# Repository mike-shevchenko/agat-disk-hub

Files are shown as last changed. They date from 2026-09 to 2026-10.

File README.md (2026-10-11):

# agat-disk-hub

KiCad project for Agat/Apple2 140K floppy disk drive connector PCB.

The Agat font used for the texts on the board's front mask resides in https://github.com/mike-shevchenko/retro-tools/tree/master/fonts/

## Использование платы

TODO

## Сборка платы

TODO

## To do

- Silk: надписи на задней стороне вдоль названия проекта сделать Justification: Left.

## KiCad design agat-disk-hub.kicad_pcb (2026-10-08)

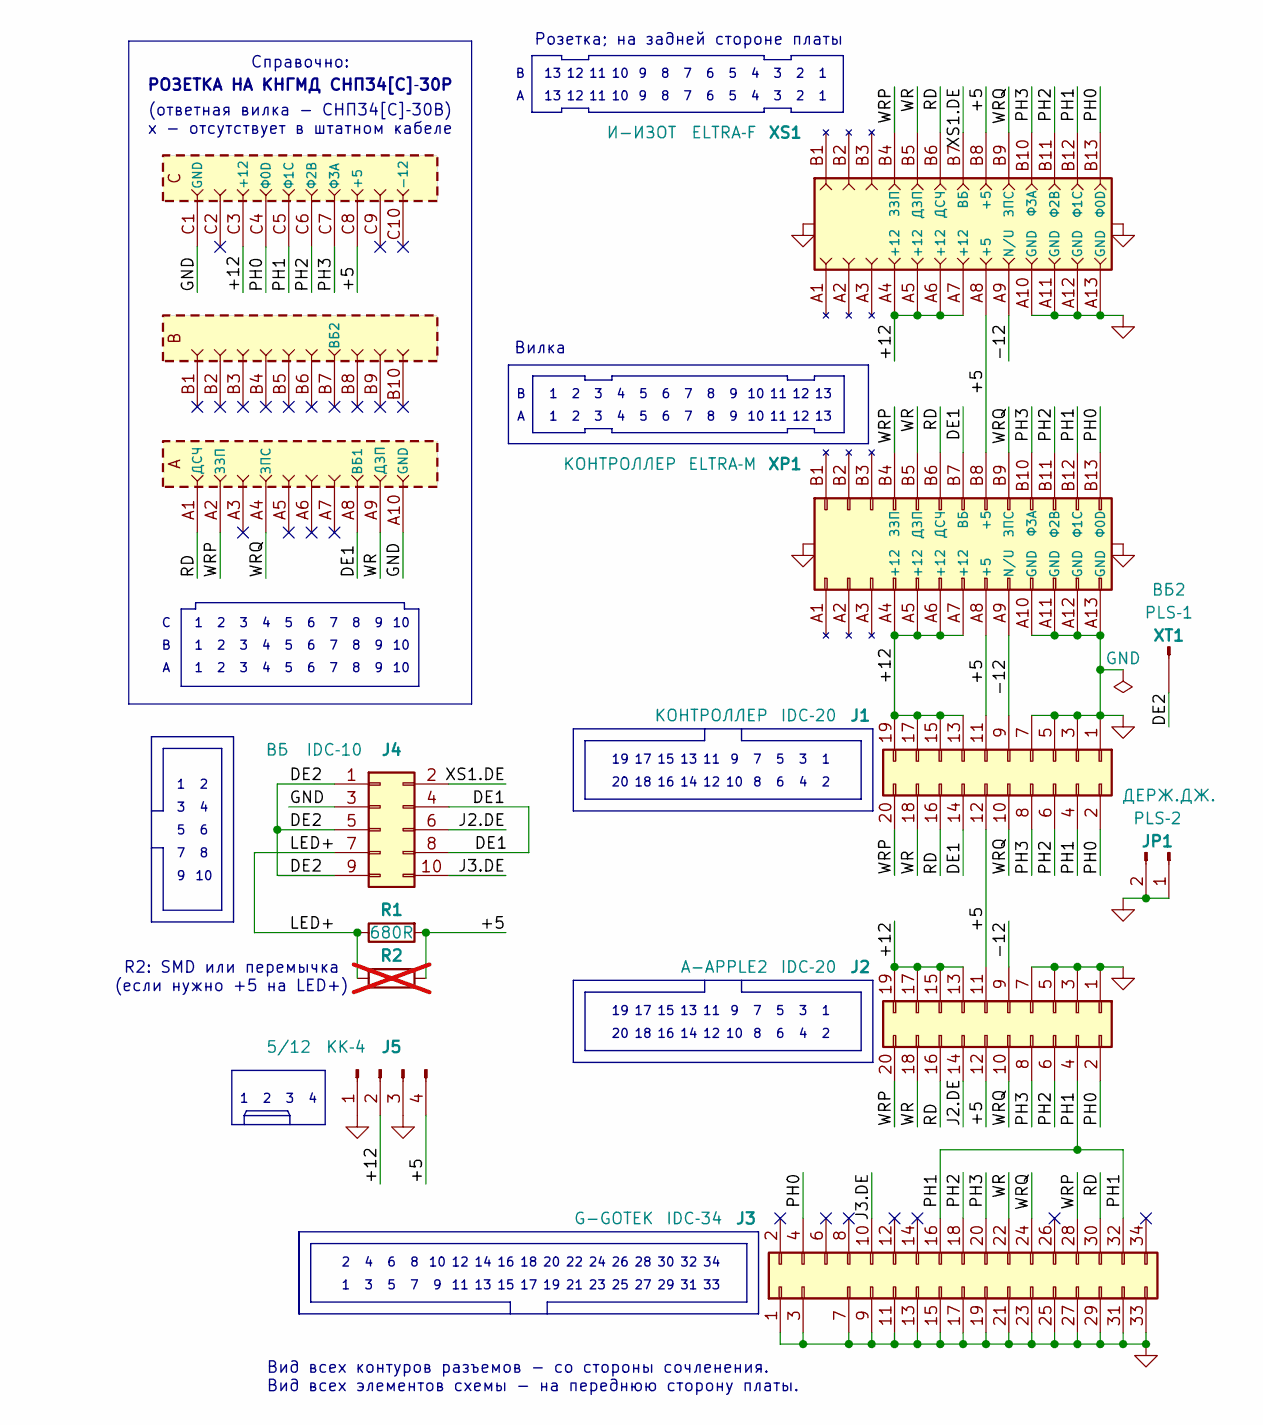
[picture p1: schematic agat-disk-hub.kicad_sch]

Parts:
J1, J2: IDC‐20; IDC-20_header_vertical_rotation180
J3: IDC‐34; IDC-34_header_vertical_rotation0
J4: IDC‐10; IDC-10_header_vertical_rotation270
J5: KK‐4; Molex_KK-4_vertical_rotation0
JP1: PLS‐2; PinHeader_1x02_P2.54mm_Vertical
R1: 680R; R_Axial_DIN0207_L6.3mm_D2.5mm_P10.16mm_Horizontal
R2: 0R; jumper_1206_solder_drop; not fitted
XP1: ELTRA‐M; Eltra-26M
XS1: ELTRA‐F; Eltra-26F
XS404: СНП34-30Р; СНП34С-30
XT1: PLS‐1; PinHeader_1x01_P2.54mm_Vertical

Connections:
/+5: J1.11, J1.12, J2.11, J2.12, J5.4, R1.2, R2.1, XP1.A8 (+5), XP1.B8 (+5), XS1.A8 (+5), XS1.B8 (+5), XS404.C8 (+5)
/+12: J1.13, J1.15, J1.17, J1.19, J2.13, J2.15, J2.17, J2.19, J5.2, XP1.A4 (+12), XP1.A5 (+12), XP1.A6 (+12), XP1.A7 (+12), XS1.A4 (+12), XS1.A5 (+12), XS1.A6 (+12), XS1.A7 (+12), XS404.C3 (+12)
/-12: J1.9, J2.9, XP1.A9 (N/U), XS1.A9 (N/U)
/DE1: J1.14, J4.4, J4.8, XP1.B7 (ВБ), XS404.A8 (ВБ1)
/DE2: J4.1, J4.5, J4.9, XT1.1 (Pin_1_1)
/J2.DE: J2.14, J4.6
/J3.DE: J3.10, J4.10
/LED+: J4.7, R1.1, R2.2
/PH0: J1.2, J2.2, J3.4, XP1.B13 (Ф0D), XS1.B13 (Ф0D), XS404.C4 (Ф0D)
/PH1: J1.4, J2.4, J3.16, J3.32, XP1.B12 (Ф1C), XS1.B12 (Ф1C), XS404.C5 (Ф1C)
/PH2: J1.6, J2.6, J3.18, XP1.B11 (Ф2B), XS1.B11 (Ф2B), XS404.C6 (Ф2B)
/PH3: J1.8, J2.8, J3.20, XP1.B10 (Ф3A), XS1.B10 (Ф3A), XS404.C7 (Ф3A)
/RD: J1.16, J2.16, J3.30, XP1.B6 (ДСЧ), XS1.B6 (ДСЧ), XS404.A1 (ДСЧ)
/WR: J1.18, J2.18, J3.22, XP1.B5 (ДЗП), XS1.B5 (ДЗП), XS404.A9 (ДЗП)
/WRP: J1.20, J2.20, J3.28, XP1.B4 (ЗЗП), XS1.B4 (ЗЗП), XS404.A2 (ЗЗП)
/WRQ: J1.10, J2.10, J3.24, XP1.B9 (ЗПС), XS1.B9 (ЗПС), XS404.A4 (ЗПС)
/XS1.DE: J4.2, XS1.B7 (ВБ)
GND: J1.1, J1.3, J1.5, J1.7, J2.1, J2.3, J2.5, J2.7, J3.1, J3.3, J3.7, J3.9, J3.11, J3.13, J3.15, J3.17, J3.19, J3.21, J3.23, J3.25, J3.27, J3.29, J3.31, J3.33, J4.3, J5.1, J5.3, JP1.1, JP1.2, XP1.A10 (GND), XP1.A11 (GND), XP1.A12 (GND), XP1.A13 (GND), XP1.SCREW_L, XP1.SCREW_R, XS1.A10 (GND), XS1.A11 (GND), XS1.A12 (GND), XS1.A13 (GND), XS1.SCREW_L, XS1.SCREW_R, XS404.A10 (GND), XS404.C1 (GND)

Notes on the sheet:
Розетка; на задней стороне платы
Справочно:
(ответная вилка - СНП34[С]‐30В) х - отсутствует в штатном кабеле
Вилка
РОЗЕТКА НА КНГМД СНП34[С]‐30Р
Вид всех контуров разъемов - со стороны сочленения. Вид всех элементов схемы - на переднюю сторону платы.
R2: SMD или перемычка (если нужно +5 на LED+)

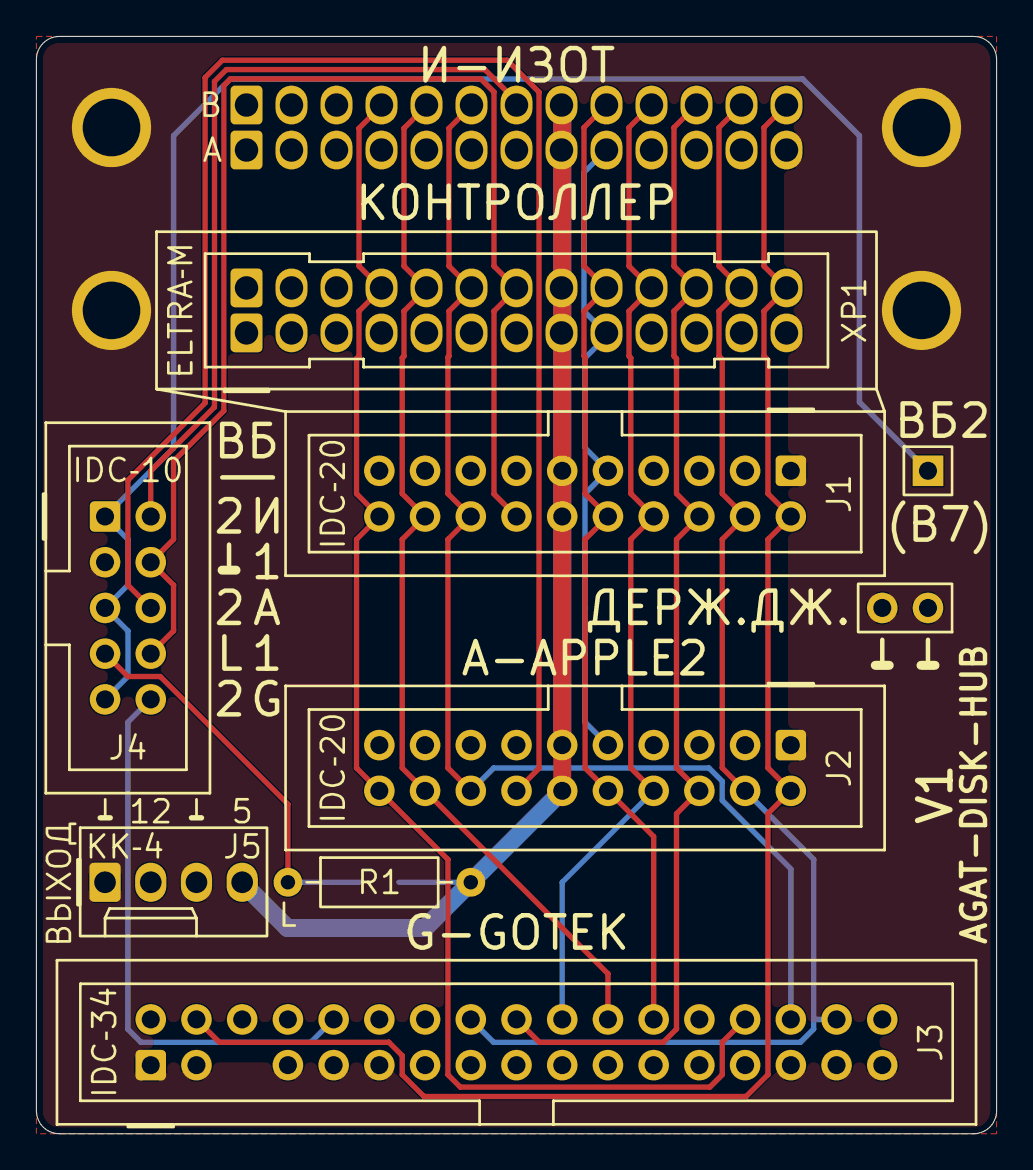
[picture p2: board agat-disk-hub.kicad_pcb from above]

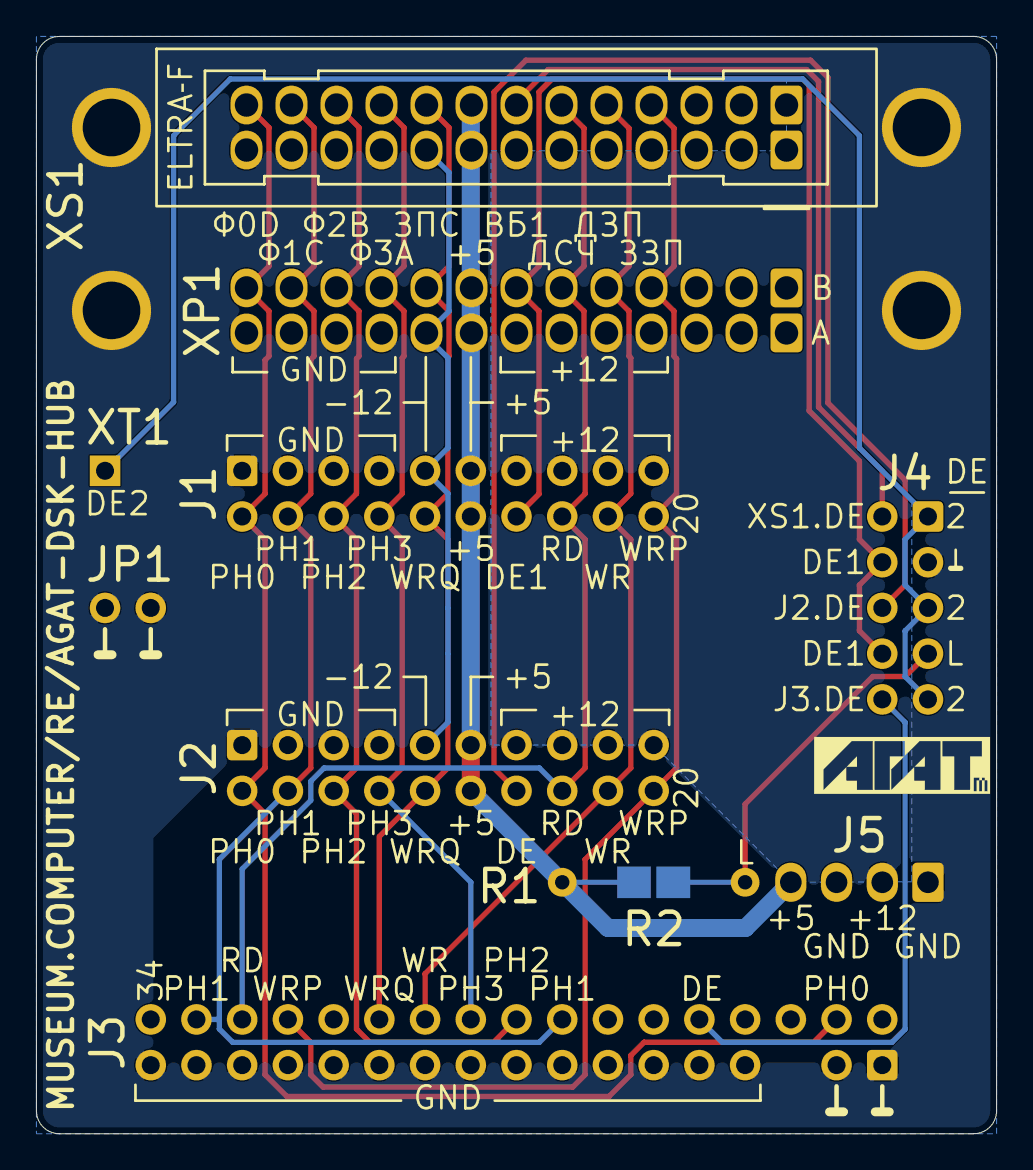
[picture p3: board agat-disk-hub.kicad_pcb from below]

Board: 2 copper layers, 53.3 x 61.0 mm, 11 parts (2 on the bottom side), 18 nets.

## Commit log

2026-09-17 add initial PCB impl: one FDC connector, small font
    [agat_disk_adapter.kicad_pcb, agat_disk_adapter.kicad_sch]
2026-09-19 add second FDC connector - Eltra male for standard Agat FDD cable
    [agat_disk_adapter.kicad_pcb, agat_disk_adapter.kicad_sch]
2026-09-19 set clearance to 0.22, adjust all traces, align J5 "fan", add J10 "-12->DE2"
    [agat_disk_adapter.kicad_pcb, agat_disk_adapter.kicad_sch]
2026-09-19 add solder drop jumper footprint; add led resistor; thermal-relief +5 trace
    [agat_disk_adapter.kicad_pcb, agat_disk_adapter.kicad_sch]
2026-09-19 flip front panel DE connector for better tracing
    [agat_disk_adapter.kicad_pcb, agat_disk_adapter.kicad_sch]
2026-09-19 create symbols and footprints for Eltras; remove unneeded solder-drops; add Agat logos
    [agat_disk_adapter.kicad_pcb, agat_disk_adapter.kicad_sch]
2026-09-19 improve silkscreen, fix DRC issues, fix jumper holder pins connection to GND; improve schematics
    [agat_disk_adapter.kicad_pcb, agat_disk_adapter.kicad_sch]
2026-09-19 refactor: rename refs for connectors and jumpers
    [agat_disk_adapter.kicad_pcb, agat_disk_adapter.kicad_sch]
2026-09-19 slightly improve pcb; fix small drc issues
    [agat_disk_adapter.kicad_pcb, agat_disk_adapter.kicad_sch]
2026-09-19 made "fan" conn pads 2.18 - close to library's 2.19, and aligned to 0.01 grid; fixed title info
    [agat_disk_adapter.kicad_pcb, agat_disk_adapter.kicad_sch]
2026-09-19 made Eltra pads oval for mechanical strength
    [agat_disk_adapter.kicad_pcb]
2026-09-19 refactor: change page size to A5-portrait (from A4-landscape)
    [agat_disk_adapter.kicad_pcb]
2026-09-19 refactor: fix tiny drawing issue on schematics
    [agat_disk_adapter.kicad_sch]
2026-09-19 refactor: move PCB to sheet center
    [agat_disk_adapter.kicad_pcb]
2026-09-21 refactor: rename project to agat-disk-hub; add URL to back side; add J5 label
    Old project name was agat_disk_adapter.
    The permanent URL of the project is now http://museum.computer/re/agat-disk-hub
    [agat-disk-hub.kicad_pcb, agat-disk-hub.kicad_sch]
2026-09-23 remove Paste from R2, so that there is no Paste layer anywhere
    [agat-disk-hub.kicad_pcb]
2026-09-24 refactor: Fab: remove stray dots next to Eltra connectors
    [agat-disk-hub.kicad_pcb]
2026-09-25 remove -12|DE2 option with JP1, rename JP3 to JP1 and move to its old place; label JP2 as FW307
    The option of supplying DE2 via +12 wire on IDC-20 or Eltra is considered dangerous for controllers
    (if someone plugs a standard cable with -12 into our board with this jumper on), so it is removed
    together with its JP1; the Net -12|DE renamed to just -12.
    JP3 (jumper parking ground) is renamed to JP1 and moved to the place previously occupied by JP1.
    Other minor adjustments:
    - Adjust a few J3 traces.
    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
    [agat-disk-hub.kicad_pcb, agat-disk-hub.kicad_sch]
2026-09-25 remove thermal reliefs on 1 mm +5 trace
    [agat-disk-hub.kicad_pcb]
2026-09-26 silkscreen: swap FW307 function and detail labels; slightly adjust some silkscreen items
    [agat-disk-hub.kicad_pcb]
2026-10-08 remap J3 phase pins, drop FW307 jumper, restore XT1; rework symbols, silkscreen and mask
    Electrical:
    - J3: PH0 moves from pin 16 to pin 4, PH1 from pin 12 to pin 16, and pin 12 is left
    unconnected; tracks rerouted to match. This is needed to enable identical wiring inside Goteks
    for use with PC/Spectrum or Apple2/Agat.
    - JP2, the FW307 jumper, is removed: J3 pin 32 is tied to PH1 for good - the PH0/PH1 remapping
    allows it for all use cases.
    - Fixed: XT1 connector was of type 2.0 mm, now is the proper 2.54 mm (since it's just one pin, it
    defines its size); adjusted the connector position.
    Schematic and symbols (refactoring only):
    - XT1 is back on the schematic on DE2, after being los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
    [agat-disk-hub.kicad_pcb, agat-disk-hub.kicad_sch]
2026-10-11 readme: close to-do on swapping +5 and +12 at J5, keep pinout
    J5 is wired GND, +12, GND, +5, which matches a PC fan header on GND and +12, puts GND opposite the
    fan's tach output and +5 on its 5 V PWM input. A fan on J5 thus runs at full speed, and a Gotek
    cable plugged into a fan header gets no +5 and stays off; swapping +5 and +12 would make both cases
    destructive.
2026-10-27 pcb silkscreen, back side: use ground symbols instead of GND for pins
